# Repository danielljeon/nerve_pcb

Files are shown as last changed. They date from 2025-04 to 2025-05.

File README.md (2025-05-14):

# nerve_pcb



PCB for CAN-based control systems dev platform.

- Firmware: [`nerve`](https://github.com/danielljeon/nerve).

---

<details markdown="1">
  <summary>Table of Contents</summary>

<!-- TOC -->
* [nerve_pcb](#nerve_pcb)
  * [1 Overview](#1-overview)
  * [2 Board Specifications](#2-board-specifications)
    * [2.1 Connectors](#21-connectors)
    * [2.2 Switches & Jumpers](#22-switches--jumpers)
  * [3 Release Notes](#3-release-notes)
    * [3.1 v0.1.0-alpha](#31-v010-alpha)
    * [3.2 v0.1.0-beta](#32-v010-beta)
    * [3.3 v0.1.0 (WIP)](#33-v010-wip)
  * [💖 Sponsors](#-sponsors)
    * [PCBWay](#pcbway)
      * [Why PCBWay?](#why-pcbway)
<!-- TOC -->

</details>

---

<a href="https://www.pcbway.com">
  PCBWay Logo
</a>

This project is sponsored by **PCBWay**. You can learn more about their valuable
support here: [💖 Sponsors/PCBWay](#pcbway).

---

## 1 Overview

| Top | Bottom |
|:---:|:---:|
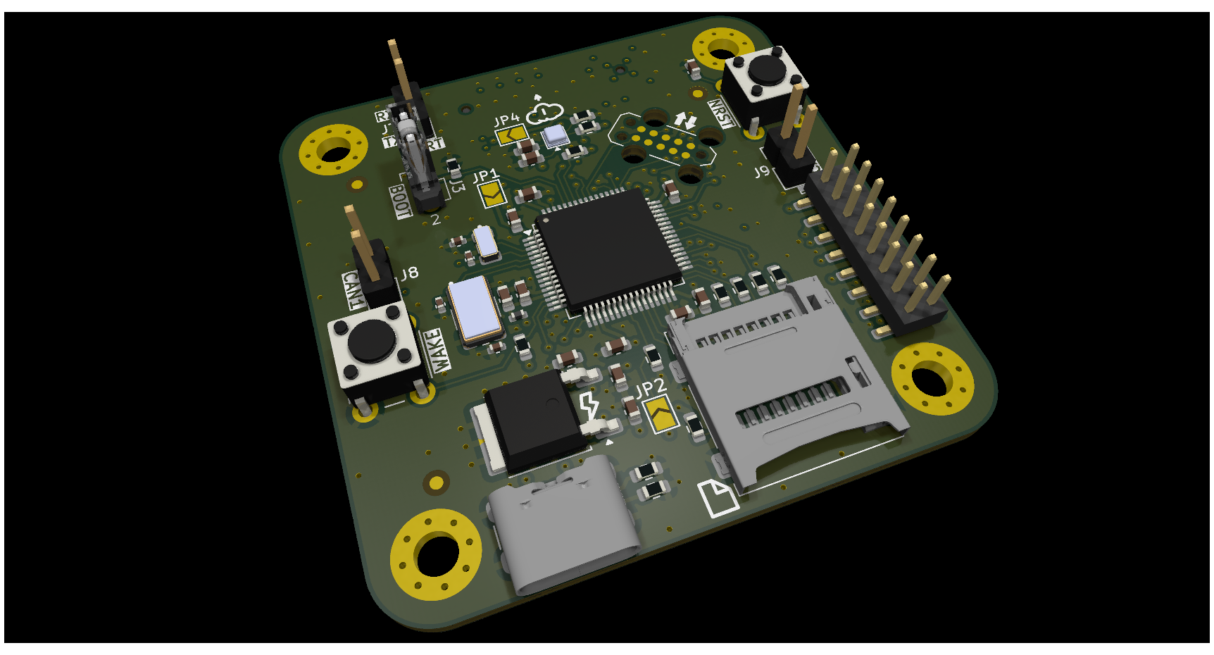
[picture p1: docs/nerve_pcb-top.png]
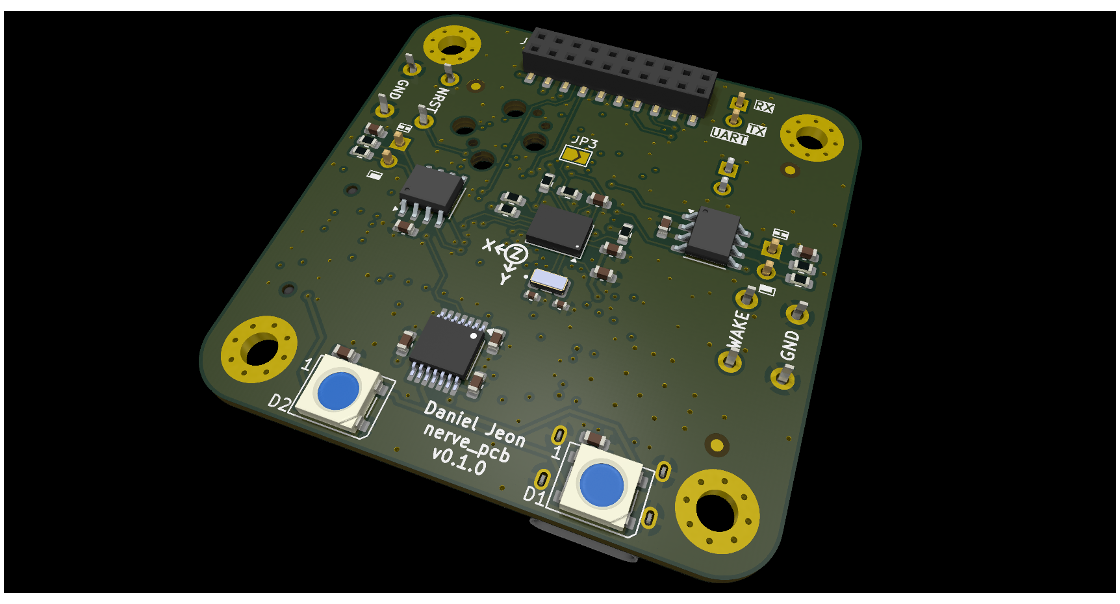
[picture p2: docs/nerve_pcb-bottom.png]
|  |  |
|  |  |

- Bottom row pictures show 4 Layer assembly variant of `nerve_pcb`,
  v0.1.0-alpha.

---

## 2 Board Specifications

### 2.1 Connectors

Connectors fixed by hardware (PCB traces or the connector itself).

| Connector | Ref | Description |
|---|:---:|---|
| Tag-Connect TC2050 | J1  | Programming/debug connector |
| USB-C 5 V power | J2  | Power only USB-C, primary 5 V source |
| BOOT0 jumper | J3  | Open for run flash memory (pull-down on open) |
| Hinge microSD card | J4  | Portable storage, see [Molex product video](https://youtu.be/YY2V8z6UK7M?t=95) |
| Top side 2x8 board-to-board | J5  | See schematic/layout for details |
| Bottom side 2x10 board-to-board | J6  | See schematic/layout for details |
| UART3 | J7  | Pin 1: UART3 RX, Pin 2: UART3 TX |
| CAN1 (Transceiver U7) | J8  | Pin 1: CAN1 High, Pin 2: CAN1 Low |
| CAN2 (Transceiver U8) | J9  | Pin 1: CAN2 High, Pin 2: CAN2 Low |

### 2.2 Switches & Jumpers

User controllable hardware and/or firmware driven inputs.

| Switch/Jumper | Ref | Description |
|---|:---:|---|
| MCU NRESET switch | SW1 | Generic 6 mm TH button, push to reset |
| MCU PA0 switch | SW2 | Generic 6 mm TH button, designed for SYS_WKUP0 |
| MCU 3.3VBATT | JP1 | Bridge to short 3.3 V supply to MCU VBAT |
| SDIO card detect jumper | JP2 | Open = card detected, closed = not detected |
| BNO085 clock select | JP3 | Open = crystal, closed = external/internal |
| BMP390 I2C address | JP4 | Open = `0x76`, closed = `0x77` |

---

## 3 Release Notes

### 3.1 v0.1.0-alpha

- Pre-release 4-layer development board variant.
- `nerve_pcb_dev`, commit 76bec6f.
    - Original commit on a different repo for automated workflow reasons.
    - Closest commit on this repo
      is [f2d1f21](https://github.com/danielljeon/nerve_pcb/commit/f2d1f21cb11d7a693d17076e7c4d2955f681dbfa).
- Order date: 2024/11/15.
- Order number: `W837000ASB3`.

### 3.2 v0.1.0-beta

- Pre-release 6-layer board variant.
    - Short-term pre-release board bring-up/testing release.
- Order date: 2025/01/13.

### 3.3 v0.1.0 (WIP)

- Minor changes from the previous `v0.1.0-beta` pre-release version.
    - CAN termination design switched from single 120 ohm termination to split
      60 ohm termination with 4.7 nF capacitor.

---

## 💖 Sponsors

### PCBWay

<a href="https://www.pcbway.com">
  PCBWay Logo
</a>

This project is sponsored by [**PCBWay**](https://www.pcbway.com), whose PCB
manufacturing services are essential in producing high-quality prototypes for
its development. Their support ensures reliable boards that meet the project's
demands.

#### Why PCBWay?

PCBWay stands out for their exceptional services and commitment to the
community:

- **PCB Manufacturing**: High-quality fabrication with options for multilayer,
  rigid-flex, and advanced designs.
- **PCB Assembly**: Comprehensive solutions, including soldering, component
  sourcing, and assembly.
- **CNC Machining & 3D Printing**: Additional prototyping options to support
  complete product development.
- **Fast Turnaround**: Reliable and quick production times to keep projects on
  schedule.
- **Support for Open Source & Education**: PCBWay actively sponsors projects and
  provides educational resources like tutorials, videos, and documentation,
  empowering developers and hobbyists.
    - This commitment to education and open-source advocacy was a key factor in
      choosing them as a partner 🙂.

Their dedication to professional-grade services and fostering innovation makes
PCBWay an invaluable partner in bringing this project to life.

Learn more here: [Why PCBWay?](https://www.pcbway.com/why.html)

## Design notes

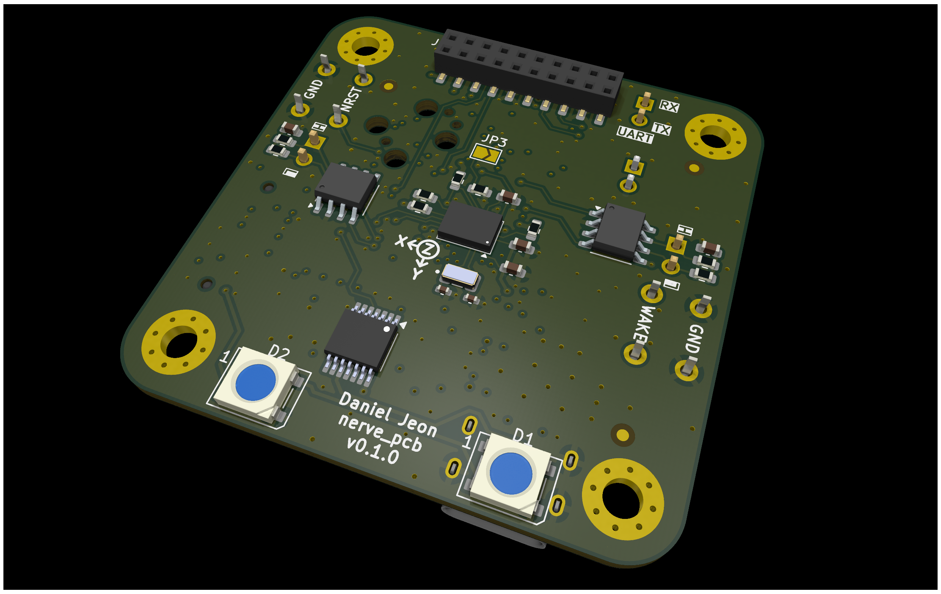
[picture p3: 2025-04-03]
docs/pictures/nerve_pcb-bottom.png

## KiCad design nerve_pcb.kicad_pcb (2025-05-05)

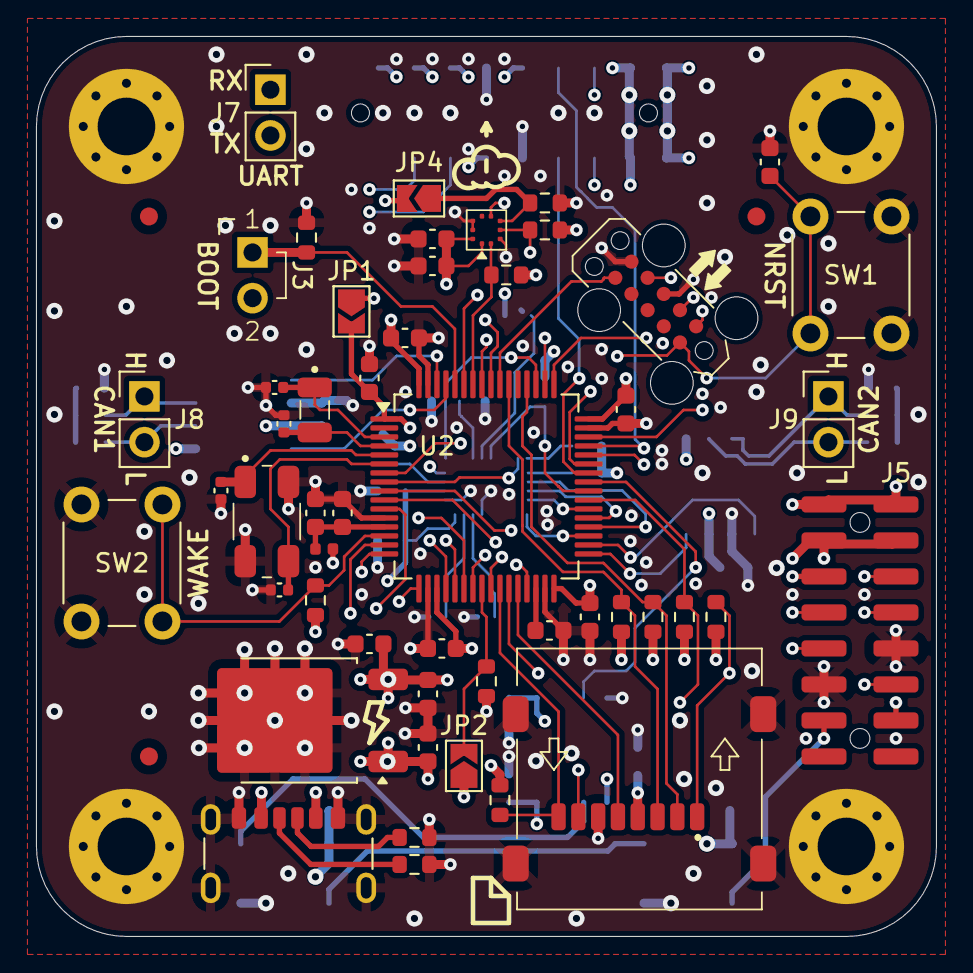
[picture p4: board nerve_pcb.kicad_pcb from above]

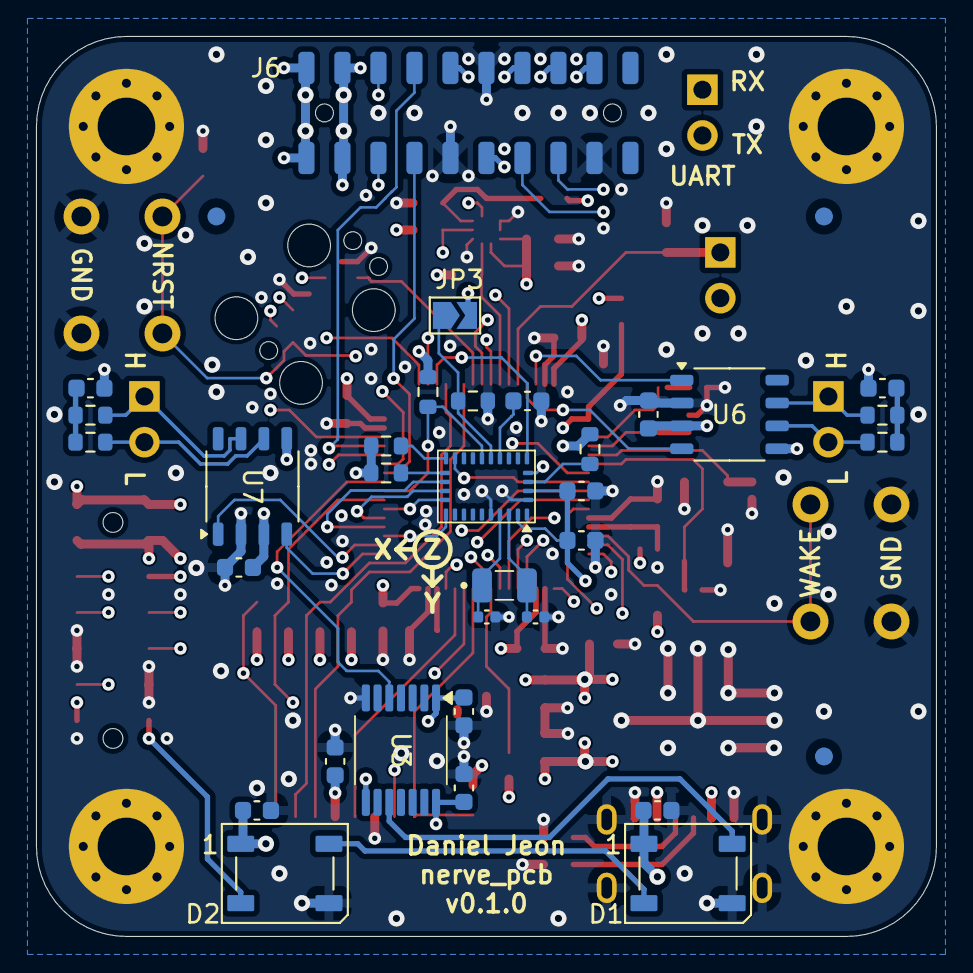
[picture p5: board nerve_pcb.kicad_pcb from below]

Board: 6 copper layers, 50.0 x 50.0 mm, 92 parts (35 on the bottom side), 75 nets.

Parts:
C1, C3: 1u; C_0603_1608Metric
C2: 10n; C_0603_1608Metric
C4, C17: 2u2; C_0603_1608Metric
C5, C6, C7, C8, C10, C11, C12, C15, C16, C20, C21, C22, C23, C26, C27, C28, C29, C30: 100n; C_0603_1608Metric
C9: 4u7; C_0603_1608Metric
C13, C14: 30p; C_0402_1005Metric
C18, C19, C24, C25: 18p; C_0402_1005Metric
C31, C32: 4n7; C_0603_1608Metric
D1, D2: WS2812B; LED_WS2812B_PLCC4_5.0x5.0mm_P3.2mm
FM1, FM2, FM3, FM4, FM5, FM6: 1mm; Fiducial_1mm_Mask2mm
H1, H2, H3, H4: M3; MountingHole_3.2mm_M3_Pad_Via
J1: TC2050-IDC; tag_connect_tc2050-idc
J2: 2171750001; molex_2171750001_usb_c_6p
J3: harwin_2p_2-54_jumper_open
J4: 472192001; molex_472192001_microsd_hinge
J5: BF030-16A-B1-0360-0277-0600-LB; bf030-16a-b1-0360-0277-0600-lb
J6: BF080-20-A-1-L-C; bf080-20-a-1-l-c
J7: UART; PinHeader_1x02_P2.54mm_Vertical
J8: CAN1; PinHeader_1x02_P2.54mm_Vertical
J9: CAN2; PinHeader_1x02_P2.54mm_Vertical
JP1, JP2, JP3, JP4: Open; SolderJumper-2_P1.3mm_Open_TrianglePad1.0x1.5mm
L1: 39n; L_0402_1005Metric
R1, R2: 5k1; R_0603_1608Metric
R3, R9, R10, R11, R12, R13, R16, R17, R18: 10k; R_0603_1608Metric
R4, R5, R6, R7, R8: 47k; R_0603_1608Metric
R14, R15: 2k2; R_0603_1608Metric
R19, R20, R21, R22: 60R; R_0603_1608Metric
SW1, SW2: SPST; SW_PUSH_6mm
U1: ld39150dt33-r; to-252-2_dpak-2-leg
U2: STM32F446RET; LQFP-64_10x10mm_P0.5mm
U3: TXB0104QPWRQ1; txb0104qpwrq1
U4: BNO085; bno085
U5: BMP390; bmp390
U6, U7: TJA1051T/3; sot96-1_soic-8
Y1: 8M; ecs_ecx-64
Y2, Y3: 32k768; ecs_ecx-34r

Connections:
+3.3VA: C1.1, C2.1, L1.2, U2.13 (VDDA)
+3.3VBATT: C10.1, J5.13, JP1.2 (B), U2.1 (VBAT)
+3V3: C4.1, C5.1, C6.1, C7.1, C8.1, C9.1, C12.1, C15.1, C22.1, C23.1, C27.1, C28.1, J1.1 (VCC), J3.2, J4.4 (VDD), J5.3, J5.4, J6.3, J6.4, JP1.1 (A), JP2.1 (A), JP3.2 (B), JP4.2 (B), L1.1, R3.1, R4.1, R5.1, R6.1, R7.1, R8.1, R11.1, R12.1, R14.1, R15.1, R16.1, R17.1, U1.3 (VO), U2.19 (VDD), U2.32 (VDD), U2.48 (VDD), U2.64 (VDD), U3.1 (V_{CCA}), U3.8 (OE), U4.3 (V_{DD}), U4.5 (PS1), U4.28 (V_{DDIO}), U5.1 (V_{DDIO}), U5.6 (CSB), U5.10 (V_{DD}), U6.5 (V_{IO}), U7.5 (V_{IO})
+5V: C3.1, C16.1, C20.1, C21.1, C29.1, C30.1, D1.1 (VDD), D2.1 (VDD), J2.A9 (VBUS), J2.B9 (VBUS), J5.1, J5.2, J6.1, J6.2, U1.1 (VI), U3.14 (V_{CCB}), U6.3 (V_{CC}), U7.3 (V_{CC})
/BOOT0: J3.1, R9.1, U2.60 (BOOT0)
/CAN1_RX: U2.61 (PB8), U6.4 (RXD)
/CAN1_TX: U2.62 (PB9), U6.1 (TXD)
/CAN2_RX: U2.33 (PB12), U7.4 (RXD)
/CAN2_TX: U2.34 (PB13), U7.1 (TXD)
/EXTI0_IMU_INT: U2.8 (PC0), U4.14 (H_INTN)
/GPIO_GPS_RST: J5.11, U2.15 (PA1)
/GPIO_IMU_P0: U2.51 (PC10), U4.6 (PS0/WAKE)
/GPIO_IMU_RST: R12.2, U2.40 (PC9), U4.11 (NRST)
/GPIO_RADIO_RST: J6.9, U2.50 (PA15)
/GPIO_SPI2_CS: U2.37 (PC6), U4.18 (H_CSN)
/HSE_IN: C13.1, U2.5 (PH0_OSC_HSE_IN), Y1.1
/HSE_OUT: C14.1, U2.6 (PH1_OSC_HSE_OUT), Y1.3
/I2C1_SCL: R17.2, U2.58 (PB6), U5.2 (SCK)
/I2C1_SDA: R16.2, U2.59 (PB7), U5.4 (SDI)
/LSE_IN: C18.1, U2.3 (PC14_OSC32_LSE_IN), Y2.1
/LSE_OUT: C19.1, U2.4 (PC15_OSC32_LSE_OUT), Y2.2
/NRST: C11.2, J1.10 (~RESET), SW1.2, U2.7 (NRST)
/PA4: J6.17, U2.20 (PA4)
/PA5: J6.15, U2.21 (PA5)
/PA6: J6.14, U2.22 (PA6)
/PA7: J6.16, U2.23 (PA7)
/PB4: J6.13, U2.56 (PB4)
/PB5: J6.12, U2.57 (PB5)
/PC1: J5.6, U2.9 (PC1)
/PC2: J5.8, U2.10 (PC2)
/PC3: J5.10, U2.11 (PC3)
/SDIO_CLK: J4.5 (CLK), U2.28 (PB2)
/SDIO_CMD: J4.3 (CMD), R6.2, U2.54 (PD2)
/SDIO_D0: J4.7 (DAT0), R5.2, U2.39 (PC8)
/SDIO_D1: J4.8 (DAT1), R4.2, U2.26 (PB0)
/SDIO_D2: J4.1 (DAT2), R8.2, U2.27 (PB1)
/SDIO_D3: J4.2 (DAT3/CD), R7.2, U2.52 (PC11)
/SDIO_DET: JP2.2 (B), R10.1, U2.24 (PC4)
/SPI2_MISO: U2.35 (PB14), U4.20 (H_SDA/H_MISO/TX)
/SPI2_MOSI: U2.36 (PB15), U4.17 (SA0/H_MOSI)
/SPI2_SCK: U2.38 (PC7), U4.19 (H_SCL/SCK/RX)
/SWCLK: J1.4 (SWCLK/TCK), U2.49 (PA14)
/SWDIO: J1.2 (SWDIO/TMS), U2.46 (PA13)
/SWO: J1.6 (SWO/TDO), U2.55 (PB3)
/TIM1_CH1_PWM: U2.41 (PA8), U3.5 (A4)
/TIM1_CH1_PWM_{5V}: D1.4 (DIN), U3.10 (B4)
/USART1_CTS: J6.5, U2.44 (PA11)
/USART1_RTS: J6.7, U2.45 (PA12)
/USART1_RX: J6.6, U2.43 (PA10)
/USART1_TX: J6.8, U2.42 (PA9)
/USART2_RX: J5.5, U2.17 (PA3)
/USART2_TX: J5.7, U2.16 (PA2)
/USART3_RX: J7.1, U2.25 (PC5)
/USART3_TX: J7.2, U2.29 (PB10)
/WS2812B_PWM: D2.2 (DOUT), J5.14
/nerve_pcb_can/CAN1+: J8.1, R20.1, U6.7 (CANH)
/nerve_pcb_can/CAN1-: J8.2, R19.1, U6.6 (CANL)
/nerve_pcb_can/CAN2+: J9.1, R22.1, U7.7 (CANH)
/nerve_pcb_can/CAN2-: J9.2, R21.1, U7.6 (CANL)
GND: C1.2, C2.2, C3.2, C4.2, C5.2, C6.2, C7.2, C8.2, C9.2, C10.2, C11.1, C12.2, C13.2, C14.2, C15.2, C16.2, C17.2, C18.2, C19.2, C20.2, C21.2, C22.2, C23.2, C24.2, C25.2, C26.2, C27.2, C28.2, C29.2, C30.2, C31.2, C32.2, D1.3 (VSS), D2.3 (VSS), H1.1, H2.1, H3.1, H4.1, J1.3 (GND), J1.5 (GND/VPROG), J2.A12 (GND), J2.B12 (GND), J2.S1 (SHIELD), J4.6 (VSS), J4.G1 (GND), J4.G2 (GND), J4.G3 (GND), J4.G4 (GND), J5.9, J5.12, J6.10, J6.11, J6.18, R1.2, R2.2, R9.2, R10.2, R13.2, R18.2, SW1.1, SW2.2, U1.2 (GND), U2.12 (VSSA), U2.18 (VSS), U2.31 (VSS), U2.47 (VSS), U2.63 (VSS), U3.7 (GND), U4.2 (GND), U4.25 (GND), U5.3 (V_{SS}), U5.8 (V_{SS}), U5.9 (V_{SS}), U6.2 (GND), U7.2 (GND), Y1.2, Y1.4
unnamed: C31.1, R19.2, R20.2
unnamed: C32.1, R21.2, R22.2
unnamed: D1.2 (DOUT), D2.4 (DIN)
unnamed: J2.A5 (CC1), R2.1
unnamed: J2.B5 (CC2), R1.1
unnamed: JP3.1 (A), R13.1, U4.10 (CLKSEL0)
unnamed: JP4.1 (A), R18.1, U5.5 (SDO)
unnamed: R3.2, SW2.1, U2.14 (PA0)
unnamed: C17.1, U2.30 (VCAP_1)
unnamed: R11.2, U4.4 (BOOTN)
unnamed: C26.1, U4.9 (CAP)
unnamed: R14.2, U4.15 (ENV_SCL)
unnamed: R15.2, U4.16 (ENV_SDA)
unnamed: C25.1, U4.27 (XIN32), Y3.2
unnamed: C24.1, U4.26 (XOUT32/CLKSEL1), Y3.1

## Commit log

2024-11-18 Add initial schematics
    [addon_gps_pcb.kicad_sch, addon_radio_pcb.kicad_sch, nerve_pcb.kicad_sch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]
2024-11-18 Update schematics
    [addon_gps_pcb.kicad_sch, addon_radio_pcb.kicad_sch, nerve_pcb.kicad_sch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]
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2024-11-18 Initial main PCB layout (no traces)
    [nerve_pcb.kicad_pcb]
2024-11-18 Clean up pre-route layout
    [nerve_pcb.kicad_pcb]
2024-11-18 Add schematic changes from PCB routing/layout
    [addon_gps_pcb.kicad_sch, addon_radio_pcb.kicad_sch, nerve_pcb.kicad_sch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]
2024-11-18 Add mounting holes to secondary schematics
    [addon_gps_pcb.kicad_sch, addon_radio_pcb.kicad_sch]
2024-11-18 Add WIP PCB
    [nerve_pcb.kicad_pcb]
2024-11-18 Update schematics for add-on PCB separation
    [addon_gps_pcb.kicad_sch, addon_radio_pcb.kicad_sch, nerve_pcb.kicad_sch]
2024-11-18 Update refs on schematics
    [addon_gps_pcb.kicad_sch, addon_radio_pcb.kicad_sch, nerve_pcb.kicad_sch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]
2024-11-18 Add breakout connectors to add-on PCBs
    [addon_gps_pcb.kicad_sch, addon_radio_pcb.kicad_sch]
2024-11-18 Clean up schematics and add footprints
    [addon_gps_pcb.kicad_sch, addon_radio_pcb.kicad_sch, nerve_pcb.kicad_sch]
2024-11-18 Add stackup note on main schematic
    [nerve_pcb.kicad_sch]
2024-11-18 Revert to 603 package sizes and add WIP PCB
    [nerve_pcb.kicad_pcb, nerve_pcb.kicad_sch, nerve_pcb_baro.kicad_sch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]
2024-11-18 Swap to 1.27mm board-to-board and WIP PCB
    [addon_gps_pcb.kicad_sch, addon_radio_pcb.kicad_sch, nerve_pcb.kicad_pcb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]
2024-11-18 Split and remove add-on board designs
    [addon_gps_pcb.kicad_sch, addon_radio_pcb.kicad_sch, nerve_pcb.kicad_pcb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]
2024-11-18 Add missing power flag
    [nerve_pcb.kicad_sch]
2024-11-18 Fix board-to-board connector pinout
    [nerve_pcb.kicad_pcb, nerve_pcb.kicad_sch]
2024-11-18 Move PCB dimensions to User Comments layer
    [nerve_pcb.kicad_pcb]
2024-11-18 Swap to 6-layer stackup
    [nerve_pcb.kicad_pcb]
2024-11-18 Move 2x8 board-to-board connector
    [nerve_pcb.kicad_pcb]
2024-11-18 Pass DRC (ERC previously passed)
    [nerve_pcb.kicad_pcb]
2024-11-19 Combine KiBot BoM directory
2024-11-19 Clean up schematics and ensure PCB parity
    [nerve_pcb.kicad_pcb, nerve_pcb.kicad_sch, nerve_pcb_baro.kicad_sch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]
2024-11-19 Adjust BMP390 address jumper and cleanup PCB
    [nerve_pcb.kicad_pcb, nerve_pcb_baro.kicad_sch]
2024-11-19 Add impedance control settings and PCB notes
    [nerve_pcb.kicad_pcb]
2024-11-19 Add differential pair CAN lines
    [nerve_pcb.kicad_pcb]
2024-11-19 Fix impedance control PCB notes
    [nerve_pcb.kicad_pcb]
2024-11-19 Update KiBot PCB PDF gen
2024-11-20 Add ground stitching vias and silkscreen cleanup
    [nerve_pcb.kicad_pcb]
2024-11-20 Add layer docs and settings
    [nerve_pcb.kicad_pcb]
2024-11-20 Nuke silkscreen and cleanup fab layers
    [nerve_pcb.kicad_pcb]
2024-11-21 Cleanup PCB
    [nerve_pcb.kicad_pcb]
2024-11-21 Add CAN 120ohm resistors
    [nerve_pcb.kicad_pcb, nerve_pcb_baro.kicad_sch, nerve_pcb_can.kicad_sch]
2024-11-21 Resolve broken links from previous commit
    [nerve_pcb.kicad_pcb]
2024-11-21 Add silkscreen drawings
    [nerve_pcb.kicad_pcb]
2024-11-22 Fix silkscreen overlapping via
    [nerve_pcb.kicad_pcb]
2024-11-22 Add Vbatt unused jumper
    [nerve_pcb.kicad_pcb, nerve_pcb.kicad_sch]
2024-11-23 Cleanup Vbatt circuit and fix silkscreen
    [nerve_pcb.kicad_pcb, nerve_pcb.kicad_sch, nerve_pcb_baro.kicad_sch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]
2024-11-25 Adjust design for easy swap to 4 layer stackup
    [nerve_pcb.kicad_pcb, nerve_pcb.kicad_sch]
2024-12-03 Add docs PCB pictures
2024-12-03 Cleanup schematic and propagate changes
    [nerve_pcb.kicad_pcb, nerve_pcb.kicad_sch]
2024-12-06 Schematic corrections
    - Add decoupling caps for sensor ICs
    - Fix clock circuits
    - Add BNO085 clock jumper
    - Minor cleanup
    [nerve_pcb.kicad_pcb, nerve_pcb.kicad_sch, nerve_pcb_baro.kicad_sch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]
2024-12-07 Major stackup revision
    [nerve_pcb.kicad_pcb]
2024-12-08 Major stackup revision and cleanup
    [nerve_pcb.kicad_pcb, nerve_pcb.kicad_sch]
2024-12-08 Fix HSE clock caps
    [nerve_pcb.kicad_pcb, nerve_pcb.kicad_sch]
2024-12-08 Simplify clock circuits
    [nerve_pcb.kicad_pcb, nerve_pcb.kicad_sch, nerve_pcb_baro.kicad_sch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]
2024-12-08 Update IMU clock circuit and cleanup
    [nerve_pcb.kicad_pcb, nerve_pcb_baro.kicad_sch, nerve_pcb_can.kicad_sch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]
2024-12-08 Swap 32k768 crystal caps to 18pF
    [nerve_pcb.kicad_pcb, nerve_pcb.kicad_sch, nerve_pcb_imu.kicad_sch]
2024-12-11 Add new symbol and footprint libraries
2024-12-11 Update J5 2x8 GPS connector
    [nerve_pcb.kicad_pcb, nerve_pcb.kicad_sch]
2024-12-11 Cleanup and update 2x10 Radio connector
    [nerve_pcb.kicad_pcb, nerve_pcb.kicad_sch, nerve_pcb_baro.kicad_sch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]
2024-12-12 Cleanup schematic and change J7 footprint
    [nerve_pcb.kicad_pcb, nerve_pcb.kicad_sch]
2024-12-12 Add WS2812Bs
    [nerve_pcb.kicad_pcb, nerve_pcb.kicad_sch, nerve_pcb_baro.kicad_sch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]
2024-12-12 Fix D2 position for symmetry
    [nerve_pcb.kicad_pcb]
2024-12-12 Fix via position to prevent USB-C short
    [nerve_pcb.kicad_pcb]
2024-12-13 Cleanup and add fiducials
    [nerve_pcb.kicad_pcb, nerve_pcb.kicad_sch]
2024-12-14 Add design notes on schematic
    [nerve_pcb.kicad_sch, nerve_pcb_baro.kicad_sch, nerve_pcb_imu.kicad_sch]
2024-12-14 Fix BNO085 circuit for SPI
    [nerve_pcb.kicad_pcb, nerve_pcb_baro.kicad_sch, nerve_pcb_can.kicad_sch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]
2024-12-15 Switch UART breakout to vertical pins
    [nerve_pcb.kicad_pcb, nerve_pcb.kicad_sch]
2024-12-16 Cleanup schematics and PCB
    [nerve_pcb.kicad_pcb, nerve_pcb.kicad_sch]
2024-12-16 Fix minor via inconsistency
    [nerve_pcb.kicad_pcb]
2024-12-17 Major routing cleanup
    [nerve_pcb.kicad_pcb]
2024-12-17 Add missing IMU silkscreen graphic
    [nerve_pcb.kicad_pcb]
2024-12-24 Fix DRC and rename pages in prep for v0.1.0-beta
    [nerve_pcb.kicad_pcb, nerve_pcb.kicad_sch, nerve_pcb_baro.kicad_sch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]
2024-12-25 Update component_library and cleanup unused pads
    [nerve_pcb.kicad_pcb, nerve_pcb.kicad_sch]
2024-12-27 Fix schematic notes
    [nerve_pcb.kicad_sch]
2025-01-03 Update component library and tables
    [nerve_pcb.kicad_pcb]
2025-01-03 Fix mounting hole thermal reliefs
    [nerve_pcb.kicad_pcb]
2025-01-05 Fix bad via position
    [nerve_pcb.kicad_pcb]
2025-01-07 Fix BNO085 circuit and touchups
    [nerve_pcb.kicad_pcb, nerve_pcb.kicad_sch, nerve_pcb_baro.kicad_sch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]
2025-01-09 Major cleanup and add missing transfer vias
    [nerve_pcb.kicad_pcb, nerve_pcb.kicad_sch]
2025-01-13 Cleanup silkscreen
    [nerve_pcb.kicad_pcb]
2025-01-22 Switch to split CAN termination
    [nerve_pcb.kicad_pcb, nerve_pcb.kicad_sch, nerve_pcb_baro.kicad_sch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]
2025-01-23 Update IMU silkscreen graphic
    [nerve_pcb.kicad_pcb]
2025-04-03 Update for KiCad 9.0 and component library
    [nerve_pcb.kicad_pcb, nerve_pcb.kicad_sch, nerve_pcb_baro.kicad_sch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]
2025-04-03 Update footprint and symbol library
2025-04-26 Add minor decoupling caps
    [nerve_pcb.kicad_pcb, nerve_pcb.kicad_sch, nerve_pcb_baro.kicad_sch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]
2025-04-26 Update component library and pictures
    [nerve_pcb.kicad_pcb, nerve_pcb.kicad_sch, nerve_pcb_imu.kicad_sch]
2025-04-26 Fix silkscreen over via
    [nerve_pcb.kicad_pcb]
2025-05-05 Add WS2812B decoupling caps and PCB cleanup
    [nerve_pcb.kicad_pcb, nerve_pcb.kicad_sch, nerve_pcb_baro.kicad_sch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]
2025-05-14 Update README.md for PCB-firmware references
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
